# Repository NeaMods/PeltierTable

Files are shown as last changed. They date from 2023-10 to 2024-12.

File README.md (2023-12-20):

# TEC sample stage   [][cc-by-nc-sa]

Here, we provide software and hardware design to build a thermoelectric cooler/heater (TEC) sample stage with precision temperature control.
The design can be modified to fit any instrument. Our implementation is compatible with [neaSNOM/neaSCOPE](https://www.neaspec.com/) microscopes.

## Software installation

This software was designed to run on Windows 10. However, we used Python modules that should allow cross-platform 
operation.

⚠️ COM port listing: when using other operation systems, please modify the COM port addressing part of the code accordingly

We suggest to install the software in a new Python environment as follows:

`(base) > conda create --name <environment_name> --file requirements.txt`

The [pyMeCom](https://github.com/spomjaksilp/pyMeCom) Python module for the communication protocol of the Controller can be installed with pip

```
(base) > conda activate <environment_name>
(<environment_name>) > conda install pip
(<environment_name>) > pip install git+https://github.com/spomjaksilp/pyMeCom.git
```

Launch the main application file:

` (<environment_name>) > python heaterApp.py`

# Components

## Main parts

- Custom-made microscope stage: [aluminum frame](CAD/frame.stl) and [heatsink](https://hu.rs-online.com/web/p/hutobordak/5040772?gb=b)
- Peltier element (Thorlabs [TECD2S](https://www.thorlabs.com/thorproduct.cfm?partnumber=TECD2S) and [TECF2S](https://www.thorlabs.com/thorproduct.cfm?partnumber=TECF2S))
- Peltier/TEC controller ([Meerstetter TEC-1091 (±4 A / ±21 V)](https://www.meerstetter.ch/products/tec-controllers/tec-1091))
- Plastic box with connectors ([ElectronicsBox.stl](CAD/ElectronicsBox.stl) and [topCover.stl](CAD/topCover.stl) file)

## Electronics

### Thermoelectric controller

The Peltier elements are controlled with a Meerstetter TEC-1091 precision Peltier temperature controller. Product page: https://www.meerstetter.ch/products/tec-controllers/tec-1091

For easy customization and assembly, we use the screw terminal block version. For the temperature sensor, we use Pt1000 RTD (https://uk.rs-online.com/web/p/rtd-sensors/1699928). 

### 3D printed box for the electronics
You will find the STL file to 3D print the box to house the electronic board and the connections. 

Our implementation looks like this:
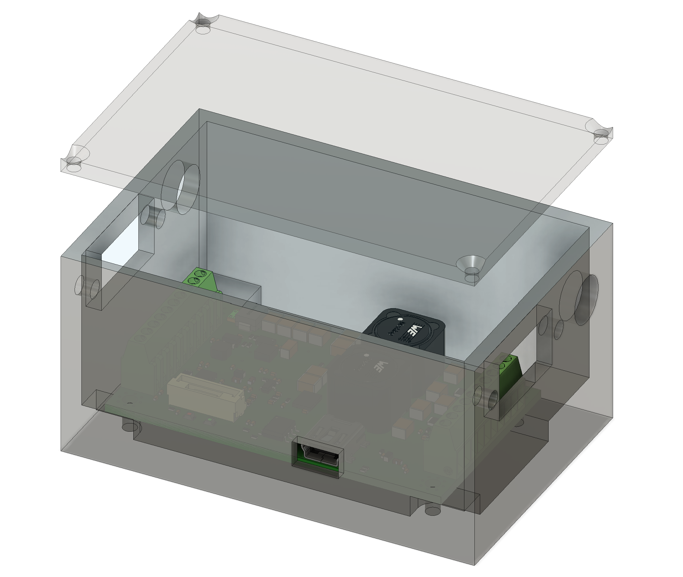
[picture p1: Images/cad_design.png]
cad_design


### Connectors

We used a D-Sub 9 pins connector for both terminals, thus all GPIO and sensor pins of the controller are available and accessible through the two D-Sub 9 pins ports on the box. The input and the output ports are DC power plugs.

### Wiring

The wiring between the controller pins and the D-Sub 9 pins pins is arbitrary. Here is an example of the sensor pins/D-Sub layout.
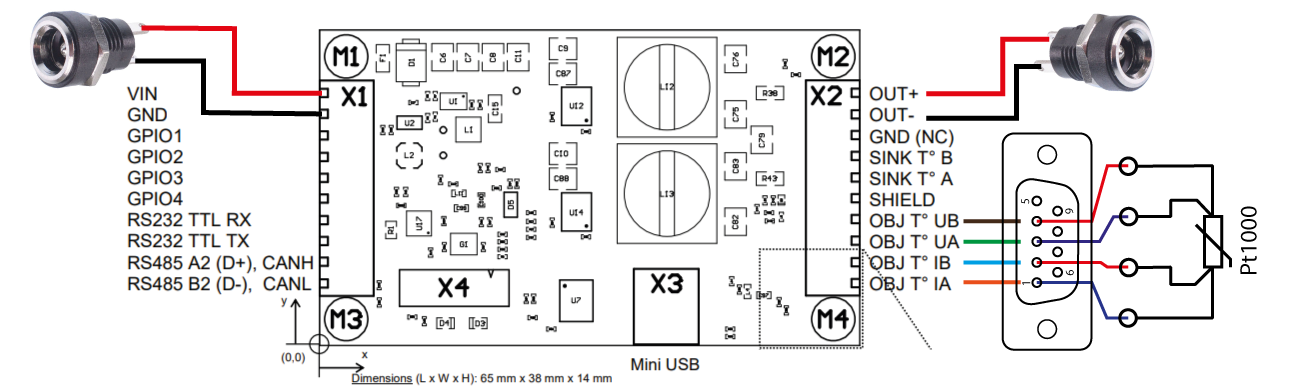
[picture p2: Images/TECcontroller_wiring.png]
wiring


Our version looks like this (colors and pins do not correspond to the design figure above):
final_box

### Peltier elements

In v1.0 we can accommodate two Peltier elements that we purchased from Thorlabs.

- TECD2S: https://www.thorlabs.com/thorproduct.cfm?partnumber=TECD2S
- TECF2S: https://www.thorlabs.com/thorproduct.cfm?partnumber=TECF2S

⚠️ To properly drive the Peltier elements, you have to give their characteristics and electronic properties (such as maximum current, resistance, voltage) to the TEC controller.

Here we provide the configuration files for our stage/peltier combinations. The configuration files can be uploaded to the controller via the [TEC Service Software](https://www.meerstetter.ch/products/tec-controllers/tec-1091) from the related downloads/software panel.

We provide here the two config files in this repository /Software/tecd2s_parameters.ini and /Software/tecf2s_parameters.ini

⚠️ It is likely that you have to retune the PID parameters of the controller. You can do this by using the autotune option of the TEC Service Software. For more information see the controller manual.

The CAD files to build the sample stage with two, replaceable Peltier elements are in the CAD directory. 
In v1.0 we modified a [commercial heatsink](https://hu.rs-online.com/web/p/hutobordak/5040772?gb=b) to dissipate the heat when cooling, which is integrated with the sample stage as the image shows below.

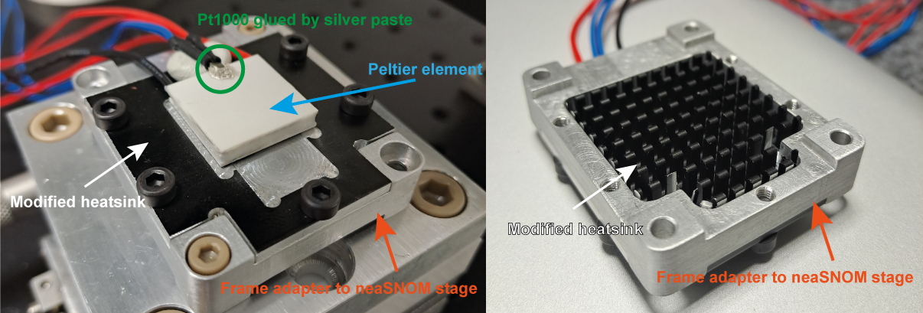
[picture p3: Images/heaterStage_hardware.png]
stage


## Performance

Temperature response and stability of the heating stage.

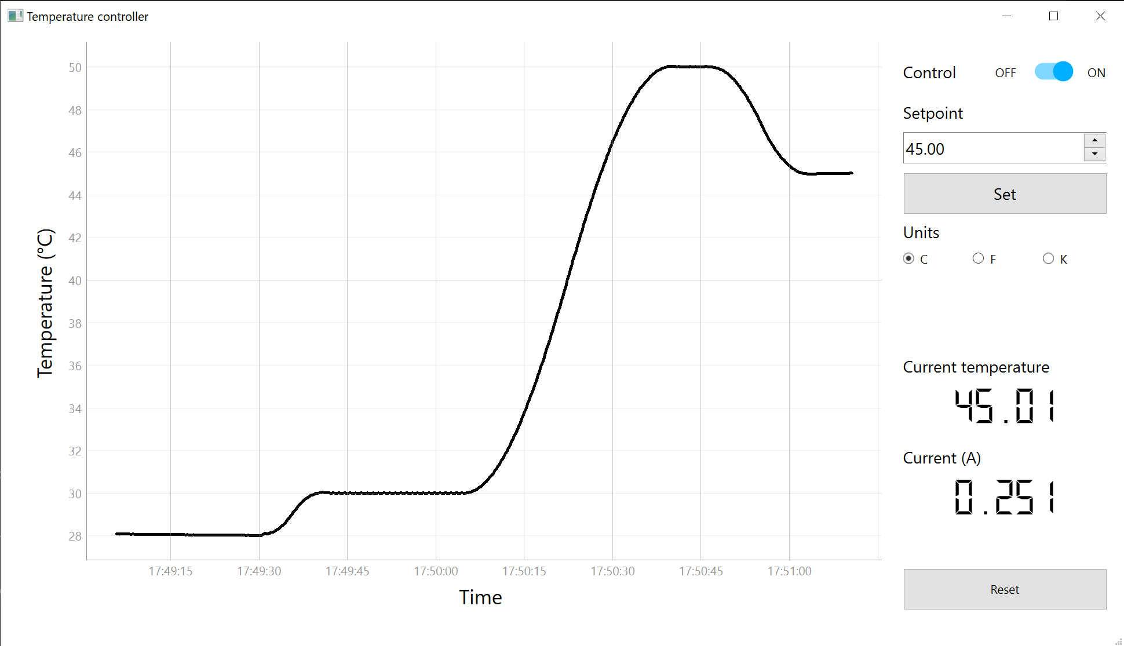
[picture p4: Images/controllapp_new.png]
controllapp_new


## License

This work is licensed under a
[Creative Commons Attribution-NonCommercial-ShareAlike 4.0 International License][cc-by-nc-sa].

[][cc-by-nc-sa]

[cc-by-nc-sa]: http://creativecommons.org/licenses/by-nc-sa/4.0/
[cc-by-nc-sa-image]: https://licensebuttons.net/l/by-nc-sa/4.0/88x31.png
[cc-by-nc-sa-shield]: https://img.shields.io/badge/License-CC%20BY--NC--SA%204.0-lightgrey.svg

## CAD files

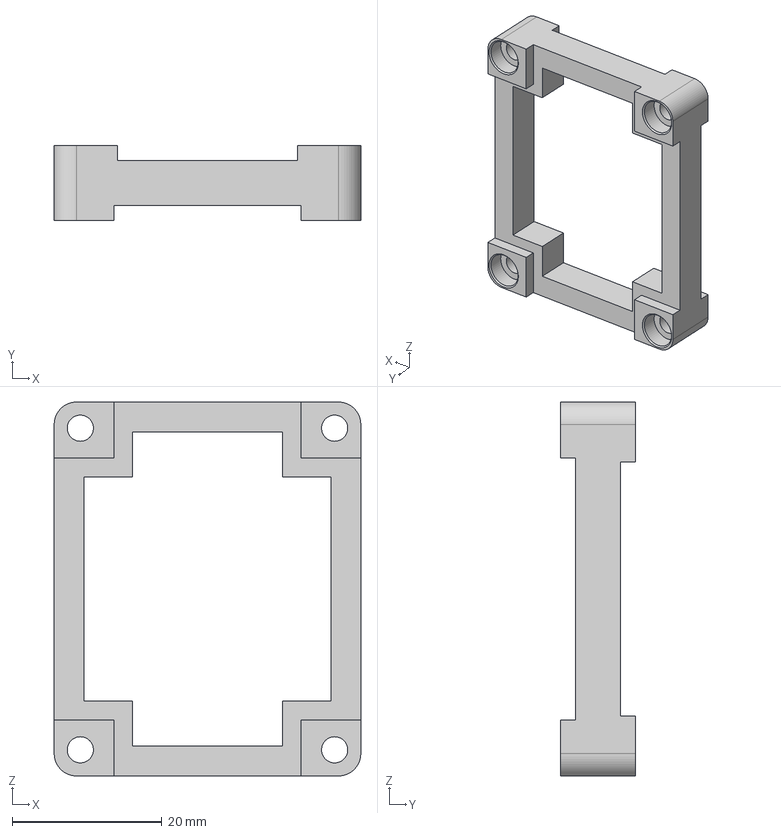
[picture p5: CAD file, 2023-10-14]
CAD/frame.step
41.0 x 10.0 x 50.0 mm

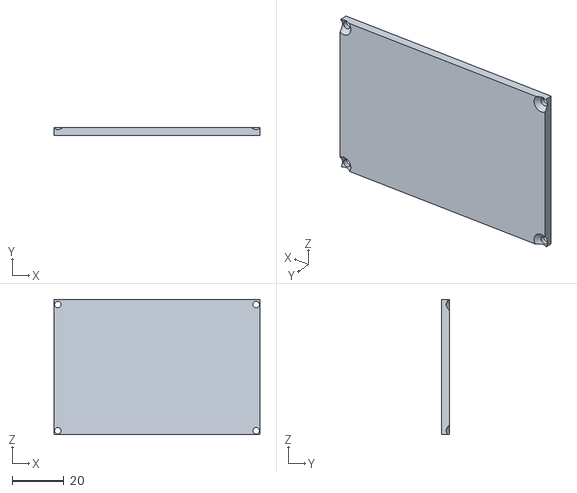
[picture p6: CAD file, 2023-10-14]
CAD/topCover.stl
80.0 x 3.00 x 52.5

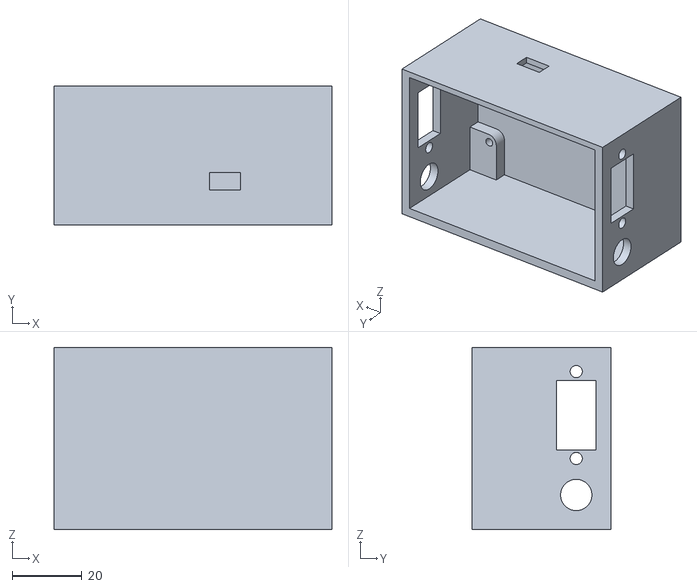
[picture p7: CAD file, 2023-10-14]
CAD/ElectronicsBox.stl
80.0 x 40.0 x 52.5

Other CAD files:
CAD/frame.stl

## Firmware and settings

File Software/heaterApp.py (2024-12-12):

#For the GUI
import sys
from PySide6 import QtWidgets
from PySide6.QtWidgets import QMessageBox
from PySide6 import QtCore, QtGui
from PySide6.QtCore import QTimer
from toggleButton import Toggle
import numpy as np
from mecom import MeComSerial, ResponseException, WrongChecksum
from serial import SerialException
import serial.tools.list_ports
import pyqtgraph as pg
from datetime import datetime
# from qt_material import apply_stylesheet

# Import the generated Python module
from ui_heaterApp import Ui_MainWindow

# default queries from command table below
DEFAULT_QUERIES = [
    "Temperature is Stable",
    "Object Temperature",
    "Target Object Temperature",
    "Actual Output Current",
    "Actual Output Voltage"
]

# syntax
# { display_name: [parameter_id, unit], }
COMMAND_TABLE = {
    "Temperature is Stable": [1200, ""],
    "Object Temperature": [1000, "degC"],
    "Target Object Temperature": [3000, "degC"],
    "Actual Output Current": [1020, "A"],
    "Actual Output Voltage": [1021, "V"],
    "Sink Temperature": [1001, "degC"],
    "Ramp Object Temperature": [1011, "degC"],
}

class controlApp(QtWidgets.QMainWindow):
    def __init__(self):
        super(controlApp,self).__init__()

        # Initialize the user interface from the generated module
        self.ui = Ui_MainWindow()
        self.ui.setupUi(self)
        self.setWindowTitle("Temperature controller")

        self.ui.toggle_power = Toggle()
        self.ui.OffLabel = QtWidgets.QLabel("OFF")
        self.ui.OnLabel = QtWidgets.QLabel("ON")
        self.ui.TogglePlaceHolder.addWidget(self.ui.OffLabel)
        self.ui.TogglePlaceHolder.addWidget(self.ui.toggle_power)
        self.ui.TogglePlaceHolder.addWidget(self.ui.OnLabel)
        self.ui.toggle_power.toggled.connect(self.SwitchControl)

        # setup stylesheet
        # apply_stylesheet(app, theme='light_blue.xml', invert_secondary=True)

        #pyqtgraph settings
        self.styles = {'color':'b', 'font-size':'20px'}
        self.ui.PlotArea.setLabel('left', 'Temperature (°C)', **self.styles)
        self.ui.PlotArea.setBackground('w')
        axis = pg.DateAxisItem()
        self.ui.PlotArea.setAxisItems({'bottom':axis})
        self.ui.PlotArea.setLabel('bottom', 'Time', **self.styles)
        self.ui.PlotArea.showGrid(x=True, y=True)
        self.ui.PlotArea.setStyleSheet("border: 0px")

        self.pen_Tplot = pg.mkPen(color=(0, 0, 0), width=5, style=QtCore.Qt.SolidLine)

        self.timer=QTimer(self)
        self.timer.setTimerType(QtCore.Qt.PreciseTimer)
        self.timer.timeout.connect(self.UpdateValues)

        self.ui.ResetButton.clicked.connect(self.ResetController)
        self.ui.SetPointButton.clicked.connect(self.SetTemperature)
        self.ui.radioButton_C.toggled.connect(self.TempSwitch)
        self.ui.radioButton_F.toggled.connect(self.TempSwitch)
        self.ui.radioButton_K.toggled.connect(self.TempSwitch)

        self.tempdata = np.array([])
        self.currentdata = []
        self.timedata = []
        self.tstart = []
        self.Npoints = 500

        self.ConnectToTEC()

    def ConnectToTEC(self):
        try:
            self.SearchCOMports()
            self.mc = MeerstetterTEC(port=self.deviceport)
            test = self.mc.get_data()
            # print(list(test.keys()))
            self.loopflag = test['Temperature is Stable'][0]
            self.ui.doubleSpinBox.setValue(test['Target Object Temperature'][0])
            print(self.loopflag)
            if  self.loopflag:
                self.ui.toggle_power.setChecked(True)
            self.timer.start(250)
        except:
            print("No TEC controller connected")
            self.NoTECfoundPopUp()

    def UpdateValues(self):
        dd = self.mc.get_data()

        T = (dd['Object Temperature'][0])
        self.tempdata = np.append(self.tempdata,T)
        if len(self.tempdata) > self.Npoints:
            self.tempdata = self.tempdata[1:]
        if self.ui.radioButton_C.isChecked():
            self.ui.lcdNumber_temp.display(T)
        elif self.ui.radioButton_F.isChecked():
            self.ui.lcdNumber_temp.display(T*9/5+32)
        elif self.ui.radioButton_K.isChecked():
            self.ui.lcdNumber_temp.display(T+273)

        C = dd['Actual Output Current'][0]
        self.currentdata.append(C)
        if len(self.currentdata) > self.Npoints:
            self.currentdata = self.currentdata[1:]
        self.ui.lcdNumber_amp.display(C)

        #n = datetime.now()
        current_time = datetime.timestamp(datetime.now()) #n.strftime("%H:%M:%S")
        self.timedata.append(current_time)
        if len(self.timedata) > self.Npoints:
            self.timedata = self.timedata[1:]
        
        self.ui.PlotArea.clear()
        if self.ui.radioButton_C.isChecked():
            self.ui.PlotArea.plot(self.timedata,self.tempdata,pen=self.pen_Tplot)
        elif self.ui.radioButton_F.isChecked():
            self.ui.PlotArea.plot(self.timedata,self.tempdata*9/5+32,pen=self.pen_Tplot)
        elif self.ui.radioButton_K.isChecked():
            self.ui.PlotArea.plot(self.timedata,self.tempdata+273,pen=self.pen_Tplot)

    def ResetController(self):
        self.mc.resetting()

    def SetTemperature(self):
        v = self.ui.doubleSpinBox.value()
        if self.ui.radioButton_F.isChecked():
            self.mc.set_temp((v-32)*5/9)
        elif self.ui.radioButton_K.isChecked():
            self.mc.set_temp(v-273)
        else:
            self.mc.set_temp(v)

    def SwitchControl(self):
        if self.ui.toggle_power.isChecked():
            try:
                self.mc.enable()
            except:
                self.NoTECfoundPopUp()
        else:
            self.mc.disable()

    def TempSwitch(self):
        radioButton = self.sender()
        test = self.mc.get_data()
        v = test['Target Object Temperature'][0]
        if radioButton.isChecked():
            if radioButton == self.ui.radioButton_C:
                self.ui.doubleSpinBox.setValue(v)
                self.ui.PlotArea.setLabel('left', 'Temperature (°C)', **self.styles)
            if radioButton == self.ui.radioButton_F:
                self.ui.doubleSpinBox.setValue(v*9/5+32)
                self.ui.PlotArea.setLabel('left', 'Temperature (F)', **self.styles)
            if radioButton == self.ui.radioButton_K:
                self.ui.doubleSpinBox.setValue(v+273)
                self.ui.PlotArea.setLabel('left', 'Temperature (K)', **self.styles)

    def SearchCOMports(self):
        comports = serial.tools.list_ports.comports()
        p = [x for x in comports if 'USB VID:PID=0403:6015 SER=DK0ADEVCA' in x.hwid]
        try:
            self.deviceport = p[0].name
            print(f"Device found on {self.deviceport}")
        except:
            print("No device was found")
            msg = QMessageBox(self)
            msg.setWindowTitle("No USB connection!")
            msg.setText("No USB connection found!")
            msg.setIcon(QMessageBox.Critical)
            msg.setStandardButtons(QMessageBox.Ok|QMessageBox.Cancel)
            msg.setInformativeText("Connect the device to the PC!")
            button = msg.exec_()

            if button == QMessageBox.Ok:
                self.SearchCOMports()
            else:
                self.close()


    def NoTECfoundPopUp(self):
        msg = QMessageBox(self)
        msg.setWindowTitle("No controller found")
        msg.setText("No TEC controller found!")
        msg.setIcon(QMessageBox.Critical)
        msg.setStandardButtons(QMessageBox.Ok)
        msg.setInformativeText("Connect or turn the controller on, and relaunch app!")
        button = msg.exec_()

        if button == QMessageBox.Ok:
            self.close()

    def closeEvent(self, event):
        try:
            self.mc.disable()
        except:
            pass

class MeerstetterTEC(object):
    """
    Controlling TEC devices via serial.
    """

    def _tearDown(self):
        self.session().stop()

    def __init__(self, port="COM9", channel=1, queries=DEFAULT_QUERIES, *args, **kwars):
        assert channel in (1, 2)
        self.channel = channel
        self.port = port
        self.queries = queries
        self._session = None
        self._connect()

    def _connect(self):
        # open session
        self._session = MeComSerial(serialport=self.port)
        # get device address
        self.address = self._session.identify()
        print("connected to {}".format(self.address))

    def session(self):
        if self._session is None:
            self._connect()
        return self._session
    
    def resetting(self):
        self.session().reset_device()

    def get_data(self):
        data = {}
        for description in self.queries:
            id, unit = COMMAND_TABLE[description]
            try:
                value = self.session().get_parameter(parameter_id=id, address=self.address, parameter_instance=self.channel)
                data.update({description: (value, unit)})
            except (ResponseException, WrongChecksum) as ex:
                self.session().stop()
                self._session = None
        return data

    def set_temp(self, value):
        """
        Set object temperature of channel to desired value.
        :param value: float
        :param channel: int
        :return:
        """
        # assertion to explicitly enter floats
        assert type(value) is float
        print("set object temperature for channel {} to {} C".format(self.channel, value))
        return self.session().set_parameter(parameter_id=3000, value=value, address=self.address, parameter_instance=self.channel)

    def _set_enable(self, enable=True):
        """
        Enable or disable control loop
        :param enable: bool
        :param channel: int
        :return:
        """
        value, description = (1, "on") if enable else (0, "off")
        print("set loop for channel {} to {}".format(self.channel, description))
        return self.session().set_parameter(value=value, parameter_name="Output Enable Status", address=self.address, parameter_instance=self.channel)

    def enable(self):
        return self._set_enable(True)

    def disable(self):
        return self._set_enable(False)

if __name__ == '__main__':

    app = QtWidgets.QApplication(sys.argv)
    ex = controlApp()
    ex.show()
    sys.exit(app.exec_())

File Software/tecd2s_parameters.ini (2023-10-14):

[SRV_PAR]
label_PAR_OBJ1_TEMPERATURE=69.998
label_PAR_SINK1_TEMPERATURE=25
label_TargetObjectTemp1=70
label_PAR_TEMP1_NOM_RAMP_NOM=70
label_PAR_PELT1_NORM_INOM=0.48
label_PAR_TEC1_Act_I=0.48
label_PAR_TEC1_Act_U=1.32
label_PAR_PID_LIM_N1=-172.1
label_PAR_PID_LIM_P1=154.5
label_PAR_TEMP1_CTRL_VAR=-2.9
label_MoniTempObj1_ADC=5922218
label_PAR_TOBJ_U1=NA
label_PAR_TOBJ_R1=1270.747
label_PAR_NTC_SINK_CH1_ADC=4092
label_PAR_TSINK_R1=4241029
label_PAR_SINK_MEAS_T1=-73.683
label_PAR_OBJECT_MEAS_T1=69.998
label_PAR_OBJ2_TEMPERATURE=NA
label_PAR_SINK2_TEMPERATURE=NA
label_TargetObjectTemp2=0
label_PAR_TEMP2_NOM_RAMP_NOM=0
label_PAR_PELT2_NORM_INOM=0
label_PAR_TEC2_Act_I=0
label_PAR_TEC2_Act_U=0
label_PAR_PID_LIM_N2=0
label_PAR_PID_LIM_P2=0
label_PAR_TEMP2_CTRL_VAR=0
label_MoniTempObj2_ADC=0
label_PAR_TOBJ_U2=0
label_PAR_TOBJ_R2=NA
label_PAR_NTC_SINK_CH2_ADC=0
label_PAR_TSINK_R2=0
label_PAR_SINK_MEAS_T2=NA
label_PAR_OBJECT_MEAS_T2=NA
label_Mon_PAR_DEVICE_TYPE=1091
label_uc_Version=5.1
label_PAR_MIN_FW_VERSION_Moni=4
label_uc_BuildNumber=688
labelM_PAR_VER_HW_VERSION=3.5
labelM_PAR_VER_HW_SERNR=24465
label_MPWR=12.27
label_M10V=4.93
label_M33V=3.29
label_MoniBasePlateTemp=33
label_PAR_OUT_CURRENT_SUM=0.48
label_PAR_DEV_TEMPM_ILIMIT=4
label_PAR_DEV_TEMPM_TLIMIT=90
label_CurrentErrorNumber=0
label_PAR_ERROR_INSTANCE=0
label_PAR_ERROR_PARAMETER=0
label_PAR_DEBUG_U1A=1.91
label_PAR_DEBUG_I1A=-0.48
label_PAR_DEBUG_U1B=0.6
label_PAR_DEBUG_I1B=0.48
label_PAR_DEBUG_REL_PWM_LEV1=6.52
label_PAR_SYM_CORR1=0
label_PAR_DEBUG_ABS_PWM_LA1=15.74
label_PAR_DEBUG_ABS_PWM_LB1=4.25
label_PAR_DEBUG_U2A=0
label_PAR_DEBUG_I2A=0
label_PAR_DEBUG_U2B=0
label_PAR_DEBUG_I2B=0
label_PAR_DEBUG_REL_PWM_LEV2=0
label_PAR_SYM_CORR2=0
label_PAR_DEBUG_ABS_PWM_LA2=-23.57
label_PAR_DEBUG_ABS_PWM_LB2=-23.57
label_PAR_SYSTICK_MAX_CYCLE=1257
label_PAR_SYSTICK_AVG_CYCLE=11
label_PAR_FAN_REL_COOL_POWER1=0
label_PAR_FAN_REL_COOL_POWER2=0
label_PAR_FAN_ACT_SPEED1=0
label_PAR_FAN_ACT_SPEED2=0
label_TimeBase_TempCtrl1=9.79
label_TimeBase_TempCtrl2=10
label_MoniPowerStageTemp1=NA
label_MoniPowerStageTemp2=NA
label_MoniPowerStageTemp3=NA
label_MoniPowerStageTemp4=NA
label_PAR_NTC_SINK_CH3_ADC=0
label_PAR_NTC_SINK_CH4_ADC=0
label_PAR_TEC1_MODE=Temperature Controller
label_PAR_TEC2_MODE=Static Current/Voltage
label_PAR_TEC_EN1=Static ON
label_PAR_TEC_EN2=Static OFF
label_PAR_TEC1_Set_I=0.1
label_PAR_TEC1_Set_U=2
label_PAR_TEC2_Set_I=1
label_PAR_TEC2_Set_U=10
label_PAR_TEC1_LIMIT_I=1.5
label_PAR_TEC1_LIMIT_U=3.7
label_PAR_TEC2_LIMIT_I=4
label_PAR_TEC2_LIMIT_U=19
label_PAR_TEC1_ERRORLIMIT_I=2
label_PAR_TEC1_ERRORLIMIT_U=4
label_PAR_TEC2_ERRORLIMIT_I=5.6
label_PAR_TEC2_ERRORLIMIT_U=22.8
label_PAR_GENERAL_MODE=Single (Independent)
label_PAR_UART_BAUDRATE1=57600
label_RS485_CH1_BaudRate=57600
label_PAR_RS485_1_RPL_DELAY=0
label_PAR_UART_BAUDRATE3=57600
label_PAR_UART_DELAY3=0
label_PAR_CONECT_WATCH_DOG=0
label_PAR_CANOPEN_NODEID=127
label_PAR_CANOPEN_BITRATE=10
label_PAR_CANOPEN_CAN1EN=Disabled
label_PAR_TEMP1_REGUL_NOM=70
label_PAR_TEMP2_REGUL_NOM=25
label_PAR_TEMP1_NOM_RAMP_T=6.831818
label_PAR_TEMP1_NOM_RAMP_S2=2.047365
label_PAR_TEMP2_NOM_RAMP_T=1
label_PAR_TEMP2_NOM_RAMP_S2=1
label_PAR_TEMP1_REGUL_KP=36.90108
label_PAR_TEMP1_REGUL_TI=0.8342206
label_PAR_TEMP1_REGUL_TD=0.5505856
label_PAR_TEMP1_REGUL_D_PT1=0.3
label_PAR_TEMP2_REGUL_KP=10
label_PAR_TEMP2_REGUL_TI=300
label_PAR_TEMP2_REGUL_TD=0
label_PAR_TEMP2_REGUL_D_PT1=0.3
label_PAR_MODELIZATION_MODE1=Peltier, Full Control
label_PAR_MODELIZATION_MODE2=Peltier, Full Control
label_PAR_PELT1_MAXI=2.1
label_PAR_PELT1_MAXDT=65.8
label_PAR_PELT_POLARITY1=Heating
label_PAR_PELT2_MAXI=15
label_PAR_PELT2_MAXDT=68
label_PAR_PELT_POLARITY2=Cooling
label_PAR_RESISTOR_RESISTANCE1=1.65
label_PAR_RESISTOR_RESISTANCE2=1.65
label_PAR_RESISTOR_MAXI1=10
label_PAR_RESISTOR_MAXI2=10
label_PAR_COOLHEAT_ONLY_LOWT1=5
label_PAR_COOLHEAT_ONLY_LOWT2=5
label_PAR_COOLHEAT_ONLY_HIGHT1=50
label_PAR_COOLHEAT_ONLY_HIGHT2=50
label_PAR_TOBJ_TADJ_A01=0
label_PAR_TOBJ_TADJ_A11=1
label_PAR_TOBJ_TADJ_A02=0
label_PAR_TOBJ_TADJ_A12=1
label_PAR_TOBJECT1_UNDER=13
label_PAR_TOBJECT1_OVER=130
label_PAR_TO_MAX_RAMP1=200
label_PAR_TOBJECT2_UNDER=13
label_PAR_TOBJECT2_OVER=65
label_PAR_TO_MAX_RAMP2=200
label_PAR_STABILITY_IND_TEMP1=1
label_PAR_STABILITY_IND_TIME1=10
label_PAR_STABILITY_IND_TEMP2=1
label_PAR_STABILITY_IND_TIME2=10
label_PAR_STABILITY_IND_MAXT1=0
label_PAR_STABILITY_IND_MAXT2=0
label_PAR_TOBJ_MIN_U1=NA
label_PAR_TOBJ_MAX_U1=NA
label_PAR_TOBJ_MIN_R1=107
label_PAR_TOBJ_MAX_R1=1792
label_PAR_TOBJ_MIN_T1=-221.3
label_PAR_TOBJ_MAX_T1=209
label_PAR_TOBJ_MIN_U2=NA
label_PAR_TOBJ_MAX_U2=NA
label_PAR_TOBJ_MIN_R2=NA
label_PAR_TOBJ_MAX_R2=NA
label_PAR_TOBJ_MIN_T2=0
label_PAR_TOBJ_MAX_T2=0
label_PAR_TSINK_TADJ_A01=0
label_PAR_TSINK_TADJ_A11=1
label_PAR_TSINK_TADJ_A02=0
label_PAR_TSINK_TADJ_A12=1
label_PAR_TSINK1_TEMP_UNDER=5
label_PAR_TSINK1_TEMP_OVER=70
label_PAR_TS_MAX_RAMP1=200
label_PAR_TSINK2_TEMP_UNDER=5
label_PAR_TSINK2_TEMP_OVER=70
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

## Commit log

2023-10-13 File transfer
    [ElectronicsBox.stl, topCover.stl]
2023-10-14 Translate UI is fixed, config.yml is not needed
    [heaterApp.py, ui_heaterApp.py]
2023-10-14 creating CAD folder
    [ElectronicsBox.stl, topCover.stl]
2023-10-14 Peltier stage init files updated
2023-10-14 frame.stl and .step added
    [frame.step, frame.stl]
2023-10-16 Stage image resized

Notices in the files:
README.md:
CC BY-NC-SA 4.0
